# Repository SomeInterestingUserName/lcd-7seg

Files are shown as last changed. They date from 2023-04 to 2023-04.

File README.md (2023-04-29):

# lcd-7seg
A 4-digit 7-segment display module based on the NXP PCF8562 driver IC. The PCB fits a Lumex LCD-S401C52TR display. With the exception of Backplanes 2-4, all other pins of the PCF8562 are broken out to headers or jumpers to allow for evaluation of advanced features.
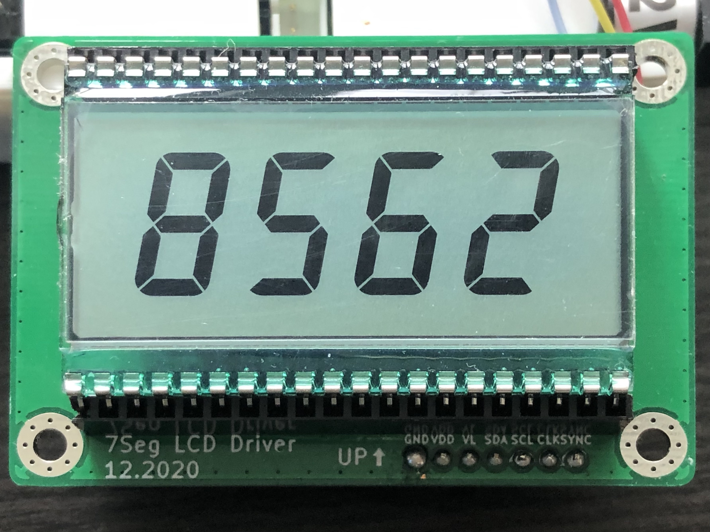
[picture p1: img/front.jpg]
Front view of the LCD module

**Note:** The NXP datasheet currently lists the PCF8562 as "Not Recommended for New Designs". The PCF85162 (note the additional "1") is a drop-in replacement for this part. However, the PCF8562 (without the "1") is still widely available, and in fact appears to be available in larger quantities at the moment (as of January 2021).

## Hardware Notes
* The PCB was designed to fit JLCPCB's design rules. Although a quick cross-check shows these rules are compatible with some other PCB fabs, please check that they meet your preferred PCB fab's specs.
* If PCBs are manufactured using the HASL (Hot-Air Solder Leveling) surface finish, small solder bumps may be left on the TSSOP footprint's pins. It is recommended to clean these with some solder wick to make IC alignment easier. This is only necessary for the PCF8562 (U1).
* This board can be hand-soldered, although some practice is recommended. All passives are 0805 size, and the PCF8562 can be quickly "drag-soldered" using plenty of flux. Be sure to closely inspect the PCF8562 pins for solder bridges and touch-up with solder wick as necessary.
* All 3-way jumpers must have **one** option selected for the module to function correctly. The default values are:
    * `A0`: `0`
    * `A1`: `0`
    * `A2`: `0`
    * `I2C ADDR`: `0x70`
    * `OSC`: `INT`
    * `VLCD`: `VDD`

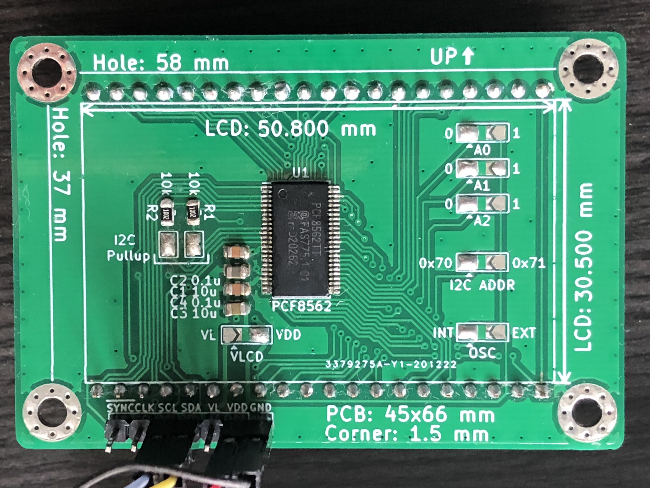
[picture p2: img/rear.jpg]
Rear view of the LCD module


## Datasheets (from mouser.com)
* [PCF8562](https://www.mouser.com/datasheet/2/302/PCF8562-1127585.pdf) (Driver IC)
* [LCD-S401C52TR](https://www.mouser.com/datasheet/2/244/LCD-S401C52TR-1141159.pdf) (LCD)

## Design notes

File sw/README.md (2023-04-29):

# Software
Library to drive the 7 Segment LCD module using the Linux I2C interface. This should work on any I2C capable Linux system, such as the BeagleBone (tested) or Raspberry Pi (untested). Note that the PCF8562 driver IC will **not** respond to read commands, so `i2cdetect` may fail to detect this device. However, it does still respond with ACK to valid write commands. 

An invalid command may cause the module to stop responding. The only fix I can think of right now is to briefly disconnect it from power.

## Build instructions
1. First compile `pcf8562.c` : `gcc -c pcf8562.c`
2. Then compile `lcd7seg.c` : `gcc -c lcd7seg.c`
3. You can now include `pcf8562.o` and `lcd7seg.o` when building your own programs.

## Directory Structure
* `pcf8562.c` / `pcf8562.h` : A generic API for the PCF8562 IC, including all documented features/configurations from the datasheet.
* `lcd7seg.c` / `lcd7seg.h` : API for this specific 4-digit 7 segment LCD module, including some helpful functions that allow you to directly print strings to the LCD module.
* `demo_lcd7seg.c` : A demo program that showcases some of the LCD module's features. Build using `gcc pcf8562.o lcd7seg.o demo_lcd7seg.c`
* `hello_pcf8562.c` : A minimal example that writes "8562" (for the PCF8562) to the LCD. Build using `gcc pcf8562.o hello_pcf8562.c`
* `Doxyfile` A Doxygen API reference. You can generate a Doxygen page with `doxygen Doxyfile`

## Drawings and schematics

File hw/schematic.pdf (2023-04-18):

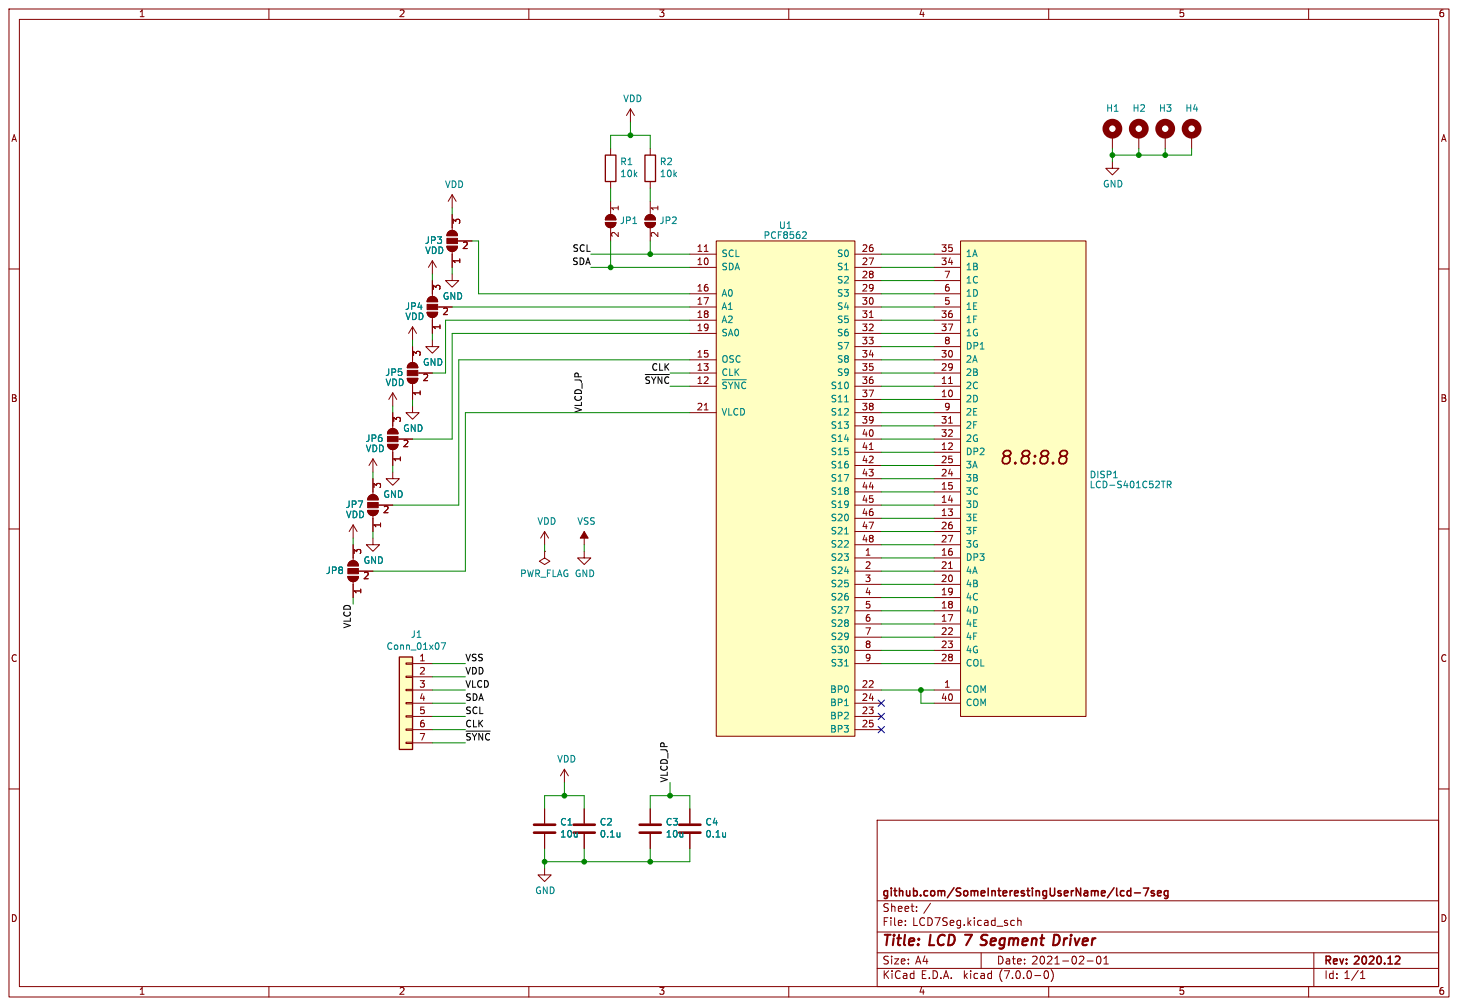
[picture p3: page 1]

Id: 1/1 Title: LCD 7 Segment Driver File: LCD7Seg.kicad_sch Sheet: / github.com/SomeInterestingUserName/lcd-7seg C4

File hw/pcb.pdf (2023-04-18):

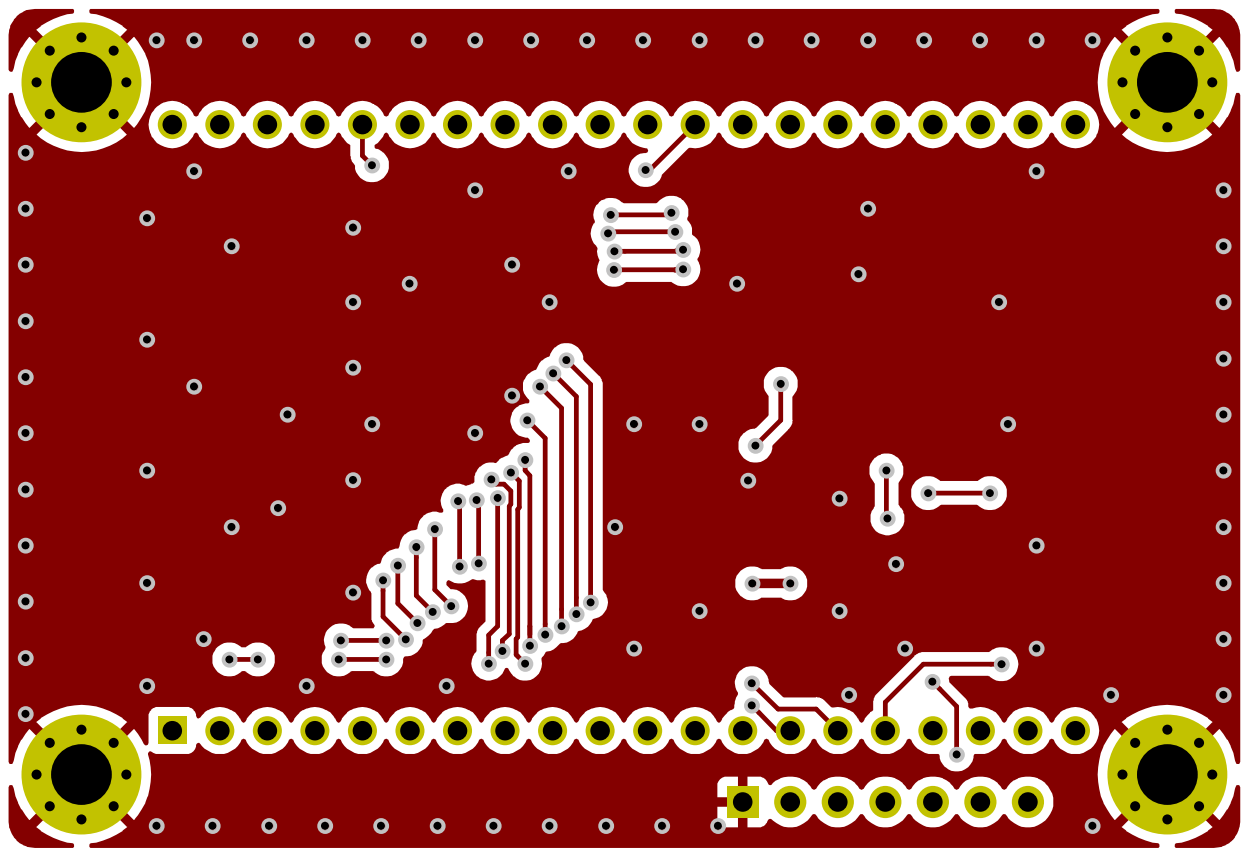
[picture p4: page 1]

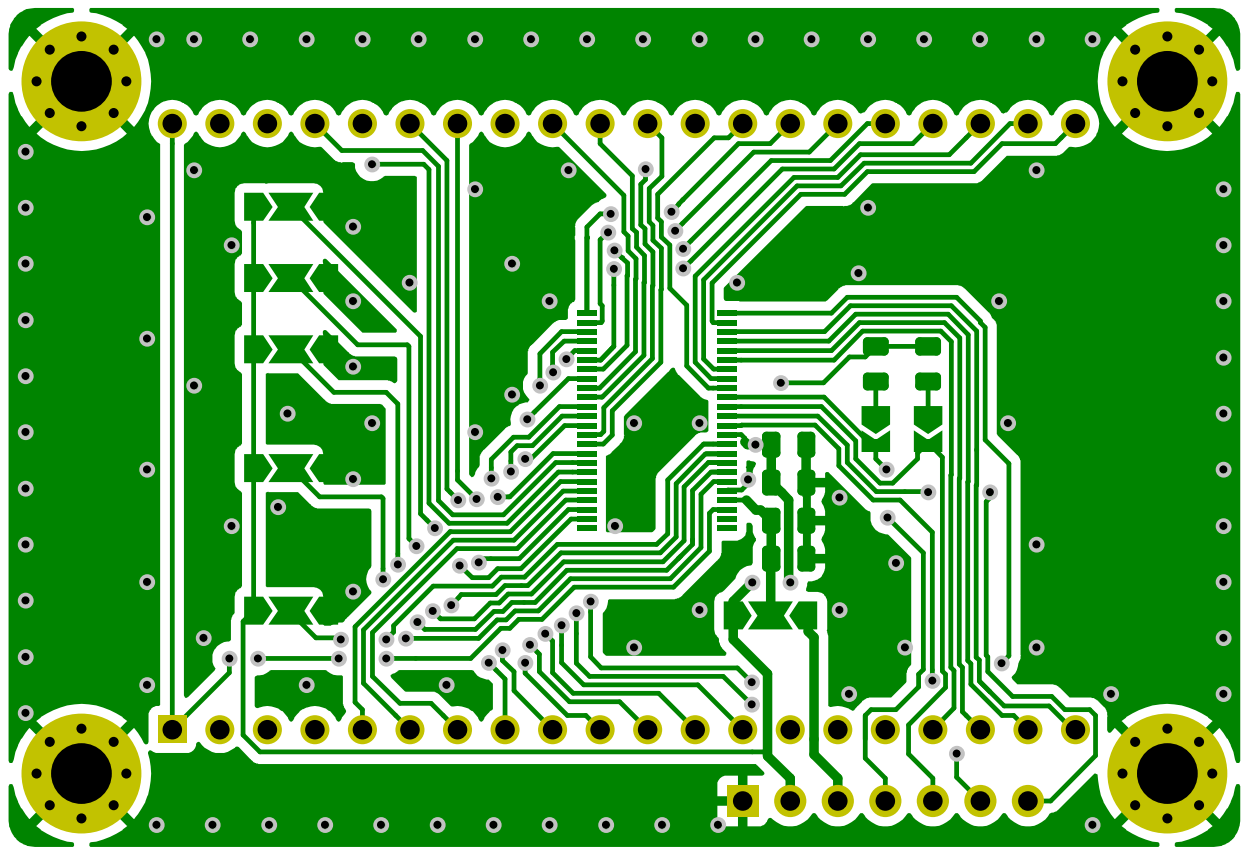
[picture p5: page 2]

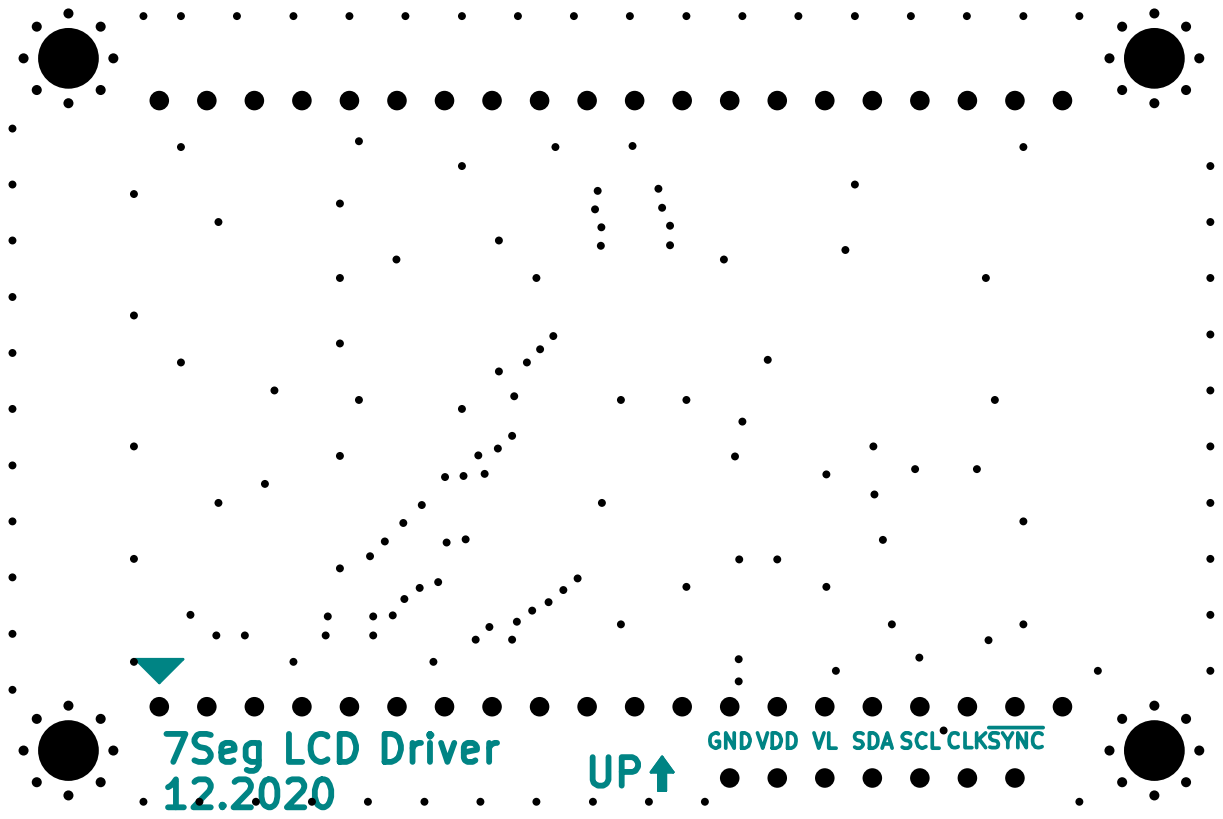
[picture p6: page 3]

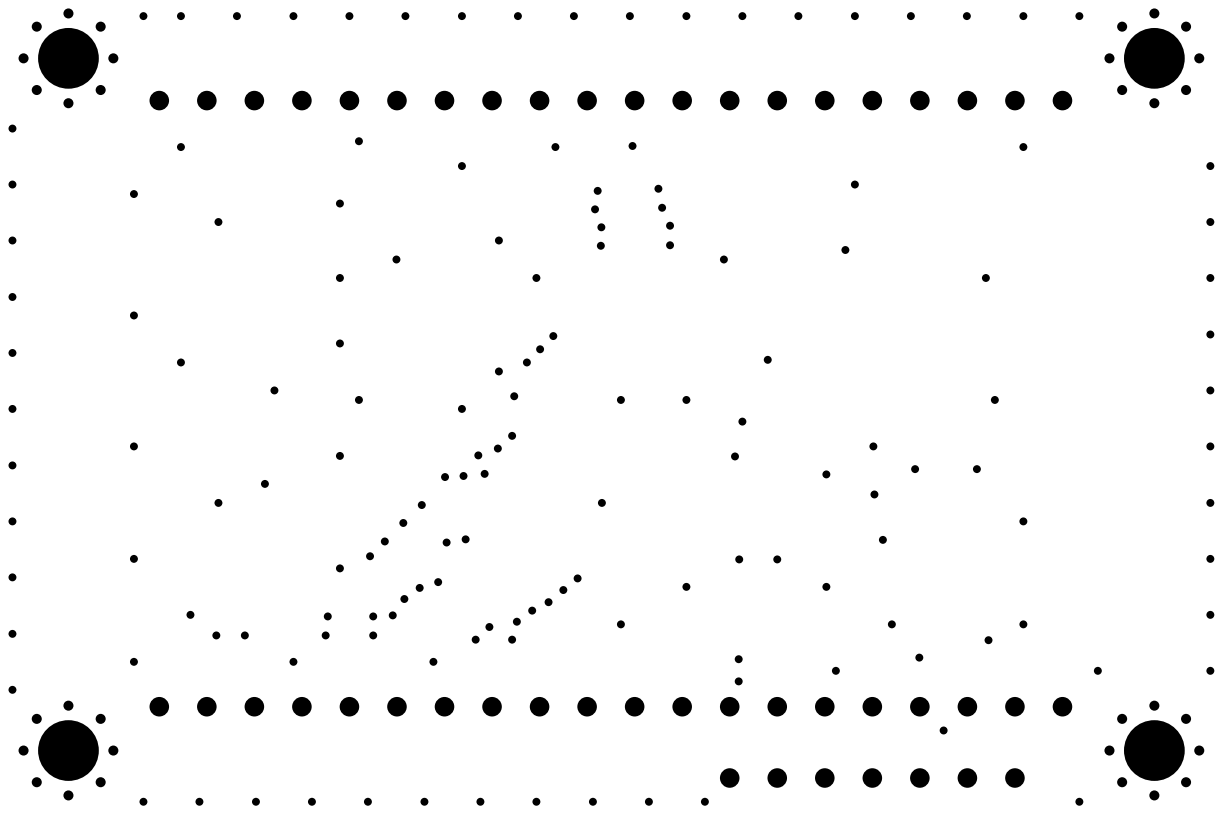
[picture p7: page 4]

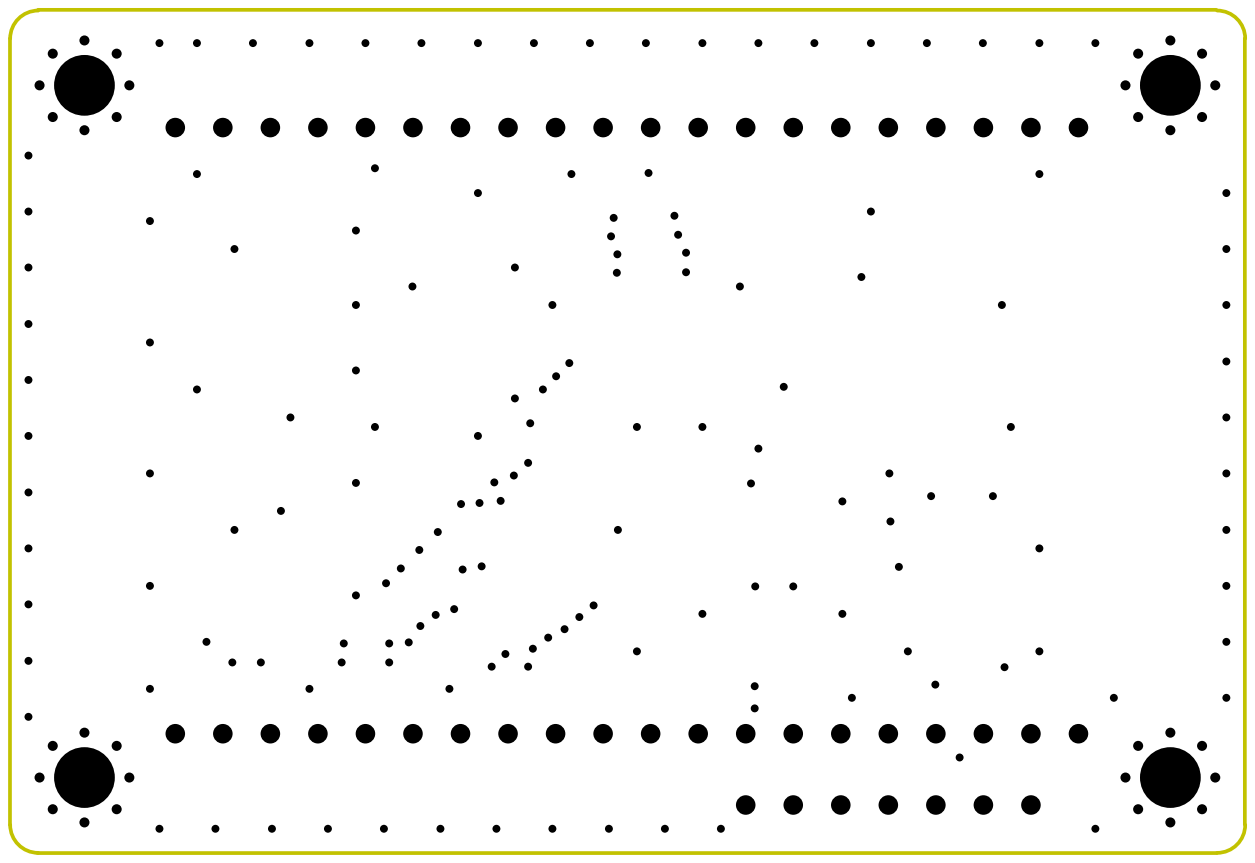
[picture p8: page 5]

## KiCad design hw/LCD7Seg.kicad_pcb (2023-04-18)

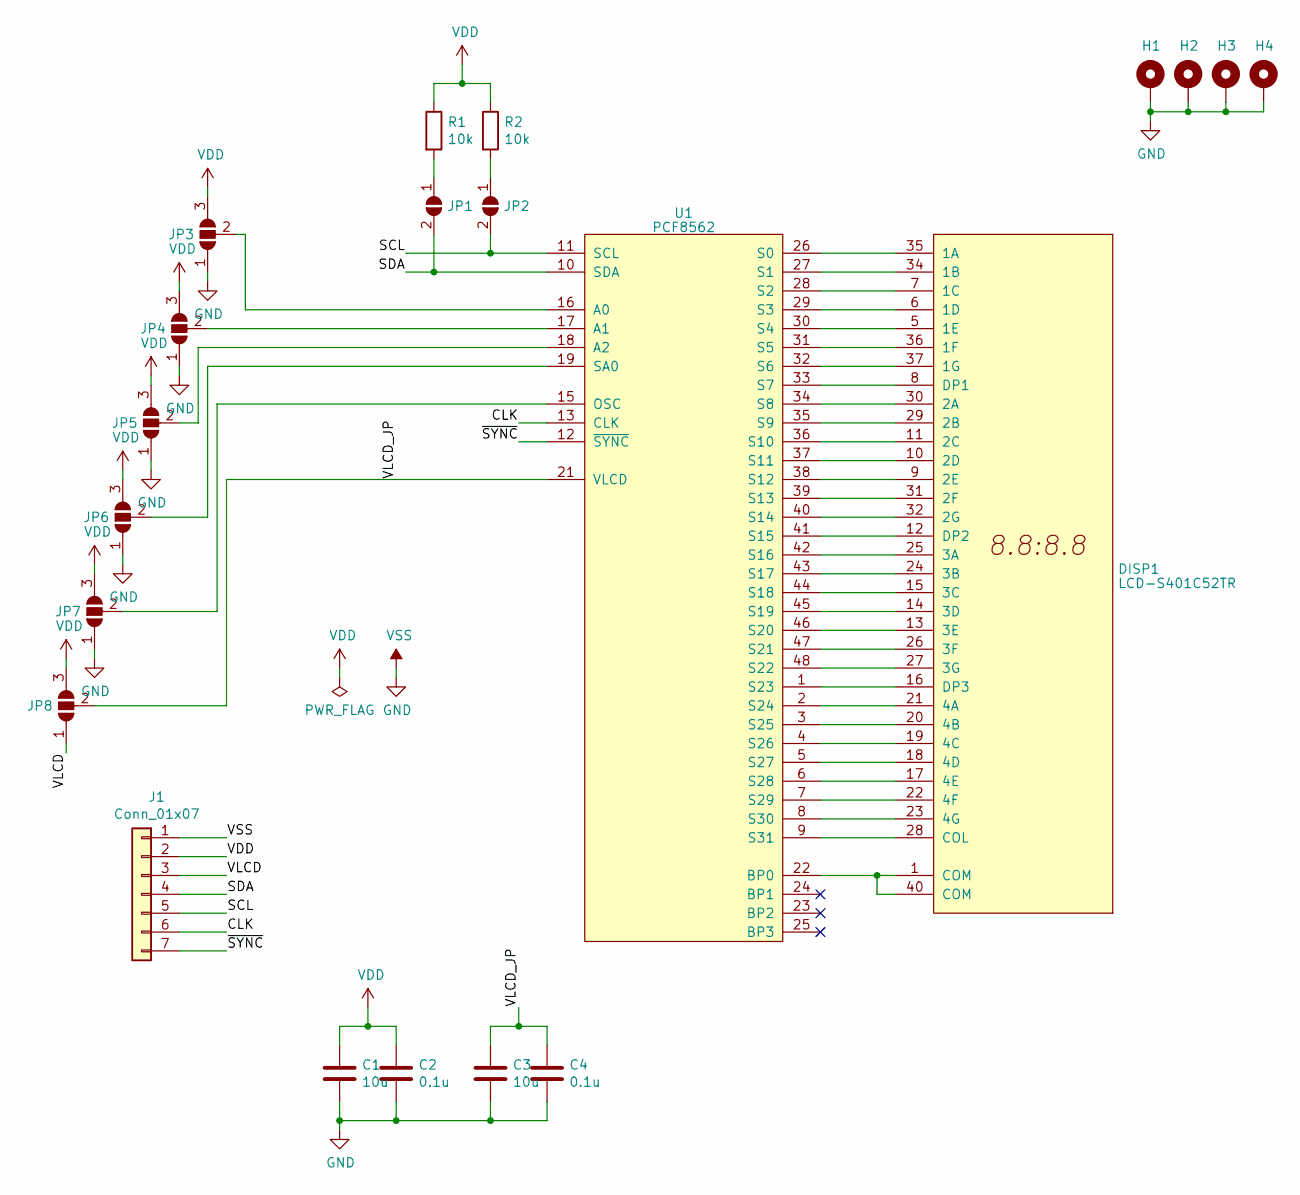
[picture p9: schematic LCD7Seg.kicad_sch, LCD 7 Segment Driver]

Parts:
C1, C3: 10u; C_0805_2012Metric
C2, C4: 0.1u; C_0805_2012Metric
DISP1: LCD-S401C52TR; S401C52TR
H1, H2, H3, H4: MountingHole_Pad; MountingHole_3.2mm_M3_Pad_Via
J1: Conn_01x07; PinHeader_1x07_P2.54mm_Vertical
JP1, JP2: SolderJumper_2_Open; SolderJumper-2_P1.3mm_Open_TrianglePad1.0x1.5mm
JP3, JP4, JP5, JP6, JP7, JP8: SolderJumper_3_Open; SolderJumper-3_P2.0mm_Open_TrianglePad1.0x1.5mm
R1, R2: 10k; R_0805_2012Metric
U1: PCF8562; TSSOP-48_6.1x12.5mm_P0.5mm

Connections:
/CLK: J1.6, U1.13 (CLK)
/SCL: J1.5, JP2.2 (B), U1.11 (SCL)
/SDA: J1.4, JP1.2 (B), U1.10 (SDA)
/VLCD: J1.3, JP8.1 (A)
/VLCD_JP: C3.1, C4.1, JP8.2 (C), U1.21 (VLCD)
/~SYNC: J1.7, U1.12 (~SYNC)
GND: C1.2, C2.2, C3.2, C4.2, H1.1, H2.1, H3.1, H4.1, J1.1, JP3.1 (A), JP4.1 (A), JP5.1 (A), JP6.1 (A), JP7.1 (A), U1.20 (VSS)
unnamed: DISP1.1 (COM), DISP1.40 (COM), U1.22 (BP0)
unnamed: DISP1.5 (1E), U1.30 (S4)
unnamed: DISP1.6 (1D), U1.29 (S3)
unnamed: DISP1.7 (1C), U1.28 (S2)
unnamed: DISP1.8 (DP1), U1.33 (S7)
unnamed: DISP1.9 (2E), U1.38 (S12)
unnamed: DISP1.10 (2D), U1.37 (S11)
unnamed: DISP1.11 (2C), U1.36 (S10)
unnamed: DISP1.12 (DP2), U1.41 (S15)
unnamed: DISP1.13 (3E), U1.46 (S20)
unnamed: DISP1.14 (3D), U1.45 (S19)
unnamed: DISP1.15 (3C), U1.44 (S18)
unnamed: DISP1.16 (DP3), U1.1 (S23)
unnamed: DISP1.17 (4E), U1.6 (S28)
unnamed: DISP1.18 (4D), U1.5 (S27)
unnamed: DISP1.19 (4C), U1.4 (S26)
unnamed: DISP1.20 (4B), U1.3 (S25)
unnamed: DISP1.21 (4A), U1.2 (S24)
unnamed: DISP1.22 (4F), U1.7 (S29)
unnamed: DISP1.23 (4G), U1.8 (S30)
unnamed: DISP1.24 (3B), U1.43 (S17)
unnamed: DISP1.25 (3A), U1.42 (S16)
unnamed: DISP1.26 (3F), U1.47 (S21)
unnamed: DISP1.27 (3G), U1.48 (S22)
unnamed: DISP1.28 (COL), U1.9 (S31)
unnamed: DISP1.29 (2B), U1.35 (S9)
unnamed: DISP1.30 (2A), U1.34 (S8)
unnamed: DISP1.31 (2F), U1.39 (S13)
unnamed: DISP1.32 (2G), U1.40 (S14)
unnamed: DISP1.34 (1B), U1.27 (S1)
unnamed: DISP1.35 (1A), U1.26 (S0)
unnamed: DISP1.36 (1F), U1.31 (S5)
unnamed: DISP1.37 (1G), U1.32 (S6)
unnamed: JP1.1 (A), R1.2
unnamed: JP2.1 (A), R2.2
unnamed: JP3.2 (C), U1.16 (A0)
unnamed: JP4.2 (C), U1.17 (A1)
unnamed: JP5.2 (C), U1.18 (A2)
unnamed: JP6.2 (C), U1.19 (SA0)
unnamed: JP7.2 (C), U1.15 (OSC)
VDD: C1.1, C2.1, J1.2, JP3.3 (B), JP4.3 (B), JP5.3 (B), JP6.3 (B), JP7.3 (B), JP8.3 (B), R1.1, R2.1, U1.14 (VDD)

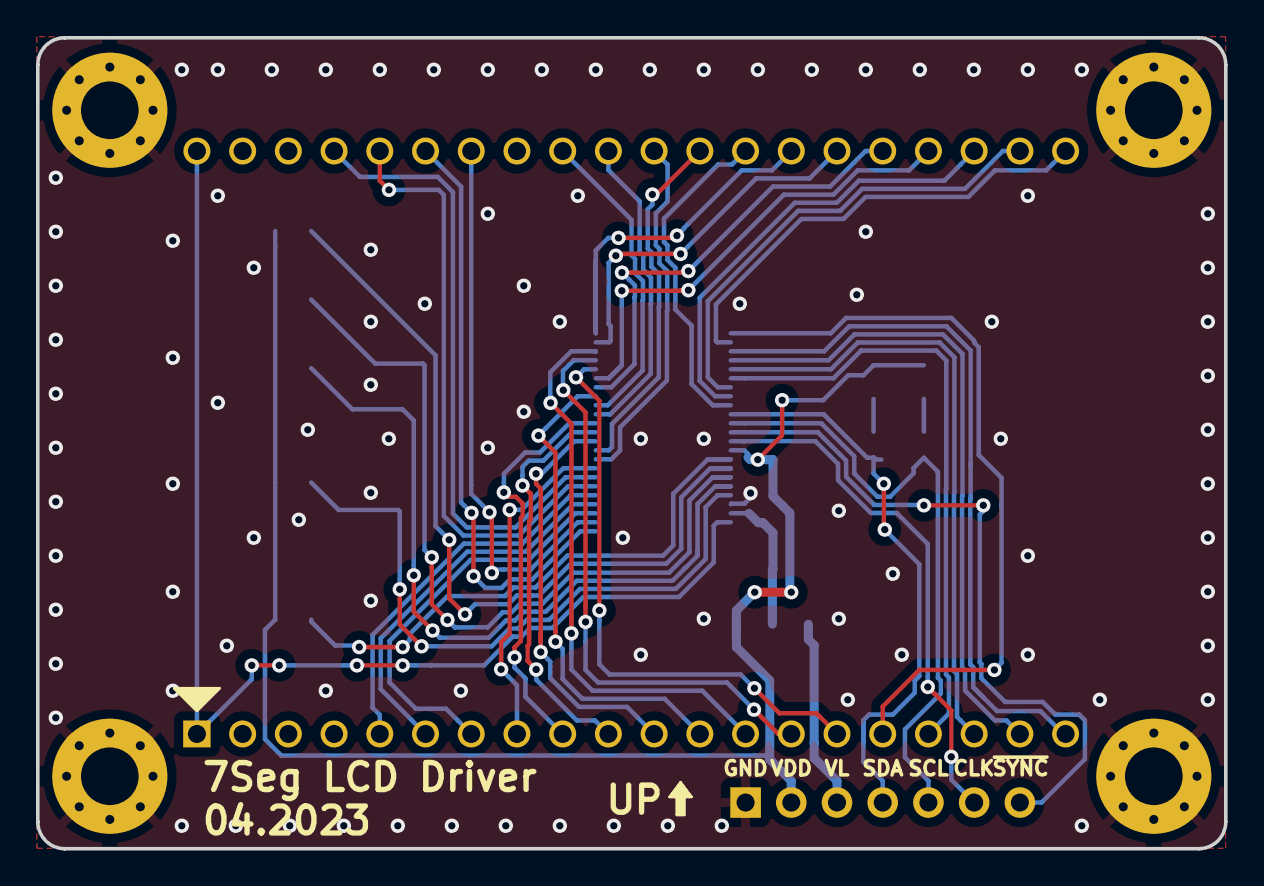
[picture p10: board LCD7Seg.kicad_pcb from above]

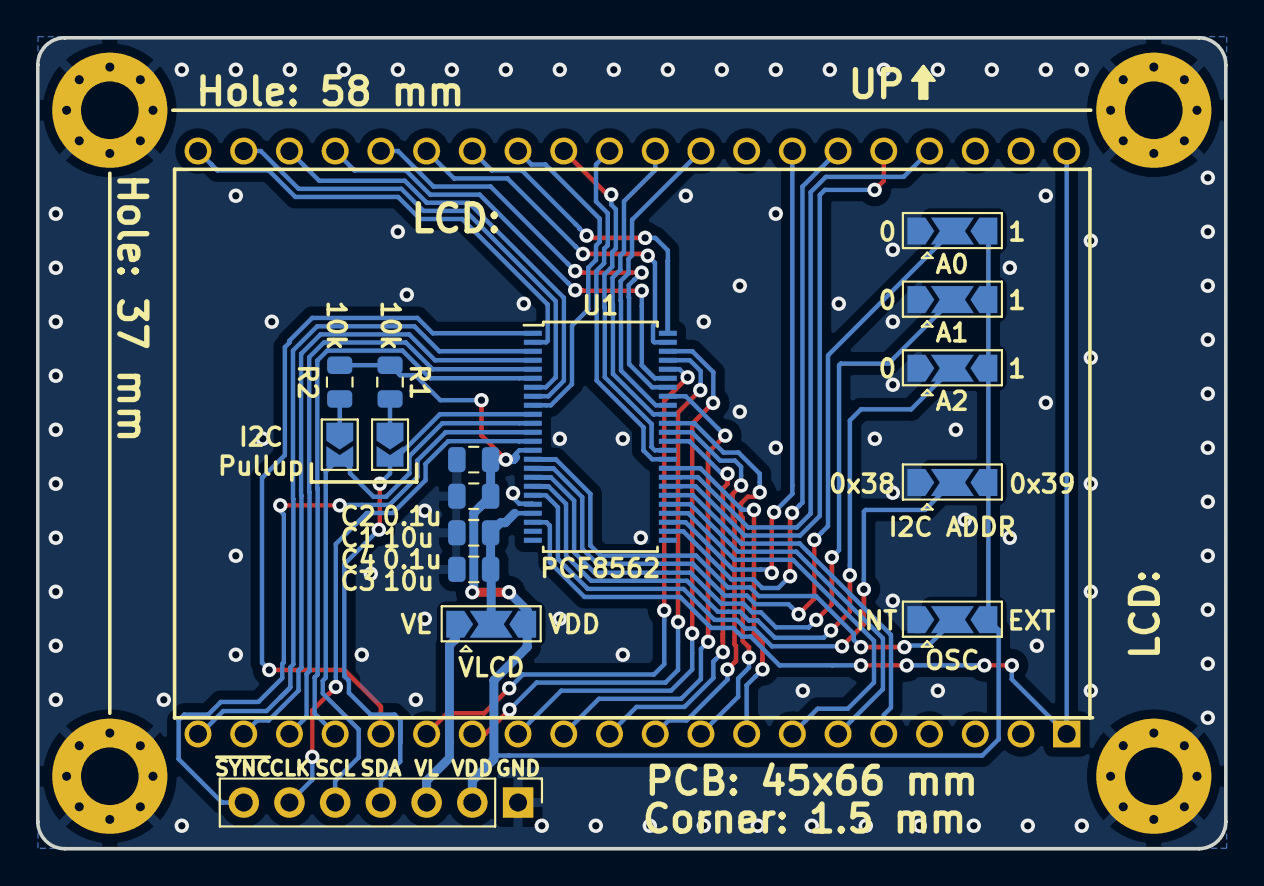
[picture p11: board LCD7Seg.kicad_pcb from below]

Board: 2 copper layers, 66.0 x 45.1 mm, 21 parts (16 on the bottom side), 48 nets.

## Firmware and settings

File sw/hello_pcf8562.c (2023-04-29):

#include <sys/ioctl.h>
#include <sys/types.h>
#include <sys/stat.h>
#include <sys/fcntl.h>
#include <stdlib.h>
#include "pcf8562.h"

int main(){
	int i2c_file;
	char * i2c_filename = "/dev/i2c-1";
	unsigned char pcf8562_addr = PCF8562_I2C_ADDR;

	if((i2c_file = open(i2c_filename,O_RDWR)) < 0){
		printf("ERROR: failed to open I2C bus\n");
		exit(1);
	}

	// Displays "8562" on the LCD
	unsigned char buf[4] = {0xfe, 0xb6, 0xbe, 0xda};
	
	PCF8562_SetMode(i2c_file, pcf8562_addr, PCF8562_MODE_ENABLE, PCF8562_MODE_BIAS_1_2, PCF8562_MODE_BACKPLANE_STATIC);
	PCF8562_WriteData(i2c_file, pcf8562_addr, 0, 4, buf);
	return 0;
}

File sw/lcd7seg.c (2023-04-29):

#include "lcd7seg.h"

unsigned char LCD7Seg_convertChar(unsigned char c){
    switch (c){
        case '0':
            return LCD7SEG_CHAR_0;
        case '1':
            return LCD7SEG_CHAR_1;
        case '2':
            return LCD7SEG_CHAR_2;
        case '3':
            return LCD7SEG_CHAR_3;
        case '4':
            return LCD7SEG_CHAR_4;
        case '5':
            return LCD7SEG_CHAR_5;
        case '6':
            return LCD7SEG_CHAR_6;
        case '7':
            return LCD7SEG_CHAR_7;
        case '8':
            return LCD7SEG_CHAR_8;
        case '9':
            return LCD7SEG_CHAR_9;
        case 'A':
            return LCD7SEG_CHAR_A;
        case 'B':
            return LCD7SEG_CHAR_B;
        case 'C':
            return LCD7SEG_CHAR_C;
        case 'D':
            return LCD7SEG_CHAR_D;
        case 'E':
            return LCD7SEG_CHAR_E;
        case 'F':
            return LCD7SEG_CHAR_F;
        case 'G':
            return LCD7SEG_CHAR_G;
        case 'H':
            return LCD7SEG_CHAR_H;
        case 'I':
            return LCD7SEG_CHAR_I;
        case 'J':
            return LCD7SEG_CHAR_J;
        case 'L':
            return LCD7SEG_CHAR_L;
        case 'N':
            return LCD7SEG_CHAR_N;
        case 'O':
            return LCD7SEG_CHAR_O;
        case 'P':
            return LCD7SEG_CHAR_P;
        case 'Q':
            return LCD7SEG_CHAR_Q;
        case 'R':
            return LCD7SEG_CHAR_R;
        case 'S':
            return LCD7SEG_CHAR_S;
        case 'T':
            return LCD7SEG_CHAR_T;
        case 'U':
            return LCD7SEG_CHAR_U;
        case '-':
            return LCD7SEG_CHAR_MINUS;
        case '_':
            return LCD7SEG_CHAR_UNDERSCORE;
        default:
            return LCD7SEG_CHAR_BLANK;
    }
}

void LCD7Seg_writeToLCD(int i2c_fd, unsigned char i2c_addr, int bank, int len, char *bytes){
    if (!bank){
        PCF8562_SetBank(i2c_fd, i2c_addr, PCF8562_BANK_IN_01, PCF8562_BANK_OUT_01);
    }
    else{
        PCF8562_SetBank(i2c_fd, i2c_addr, PCF8562_BANK_IN_23, PCF8562_BANK_OUT_23);
    }
	PCF8562_WriteData(i2c_fd, i2c_addr, 0, len, bytes);
}

void LCD7Seg_stringToLCD(int i2c_fd, unsigned char i2c_addr, int bank, int len, char * str, unsigned char dp){
    unsigned char buf[4];
    for(int i=0; i<4; ++i){
        if(i >= len || str[i] == 0){
            buf[i] = LCD7SEG_CHAR_BLANK;
        }
        buf[i] = LCD7Seg_convertChar(str[i]);
        if (dp & (0b10000000 >> i)){
            buf[i] |= LCD7SEG_CHAR_DP;
        }
    }
    LCD7Seg_writeToLCD(i2c_fd, i2c_addr, bank, 4, buf);
}

void LCD7Seg_stringToLCDSimple(int i2c_fd, unsigned char i2c_addr, char * str){
    LCD7Seg_stringToLCD(i2c_fd, i2c_addr, 0, 4, str, 0);
}	

void LCD7Seg_init(int i2c_fd, unsigned char i2c_addr){
    PCF8562_SetMode(i2c_fd, i2c_addr, PCF8562_MODE_ENABLE, PCF8562_MODE_BIAS_1_3, PCF8562_MODE_BACKPLANE_STATIC);
}

void LCD7Seg_enableBlink(int i2c_fd, unsigned char i2c_addr, unsigned char alternate){
    unsigned char blinkMode;
    if(alternate){
        blinkMode = PCF8562_BLINK_MODE_ALTERNATE;
    }
    else{
        blinkMode = PCF8562_BLINK_MODE_NORMAL;
    }
    PCF8562_SetBlink(i2c_fd, i2c_addr, blinkMode, PCF8562_BLINK_FREQ_2);
}

void LCD7Seg_disableBlink(int i2c_fd, unsigned char i2c_addr){
    PCF8562_SetBlink(i2c_fd, i2c_addr, PCF8562_BLINK_MODE_NORMAL, PCF8562_BLINK_FREQ_DISABLE);
}

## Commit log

2021-01-24 Add Hardware Files
    [LCD7Seg.kicad_pcb, LCD7Seg.sch]
2021-02-02 Add info to schematic and pcb files
    [LCD7Seg.kicad_pcb, LCD7Seg.sch]
2021-02-02 Change i2c address on pcb silkscreen--should be 0x38 and 0x39
    [LCD7Seg.kicad_pcb]
2023-04-18 Migrate to KiCad 7.0
    Old files can be found at `legacy/`
    KiCad's PCB editor does fills a bit differently now, changing the copper
    fill pattern on the board. This warranted a new revision code on the
    PCB.
    [LCD7Seg.kicad_pcb, LCD7Seg.kicad_sch, LCD7Seg.sch]
2023-04-18 Add PDFs of schematic and PCB
